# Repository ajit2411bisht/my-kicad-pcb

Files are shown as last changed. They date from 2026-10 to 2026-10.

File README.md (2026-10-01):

# ESP32-C3 PCB Design

## Overview

This project contains a custom PCB design based on the ESP32-C3.

The PCB was designed using KiCad and includes the main ESP32-C3 circuit along with sensor and user-interface sections.

## Tools Used

- KiCad

## Project Files

- `esp32demoproject.kicad_pro` - KiCad project file
- `esp32demoproject.kicad_pcb` - PCB layout
- `esp32-c3-02.kicad_sch` - ESP32-C3 schematic
- `sensors.kicad_sch` - Sensor section schematic
- `user_interface.kicad_sch` - User interface schematic

## Features

- ESP32-C3 based design
- Sensor interface
- User interface section
- Custom PCB layout
- Hierarchical schematic design

## PCB Design

The PCB layout was designed and reviewed using KiCad.

## Author

Ajit Bisht

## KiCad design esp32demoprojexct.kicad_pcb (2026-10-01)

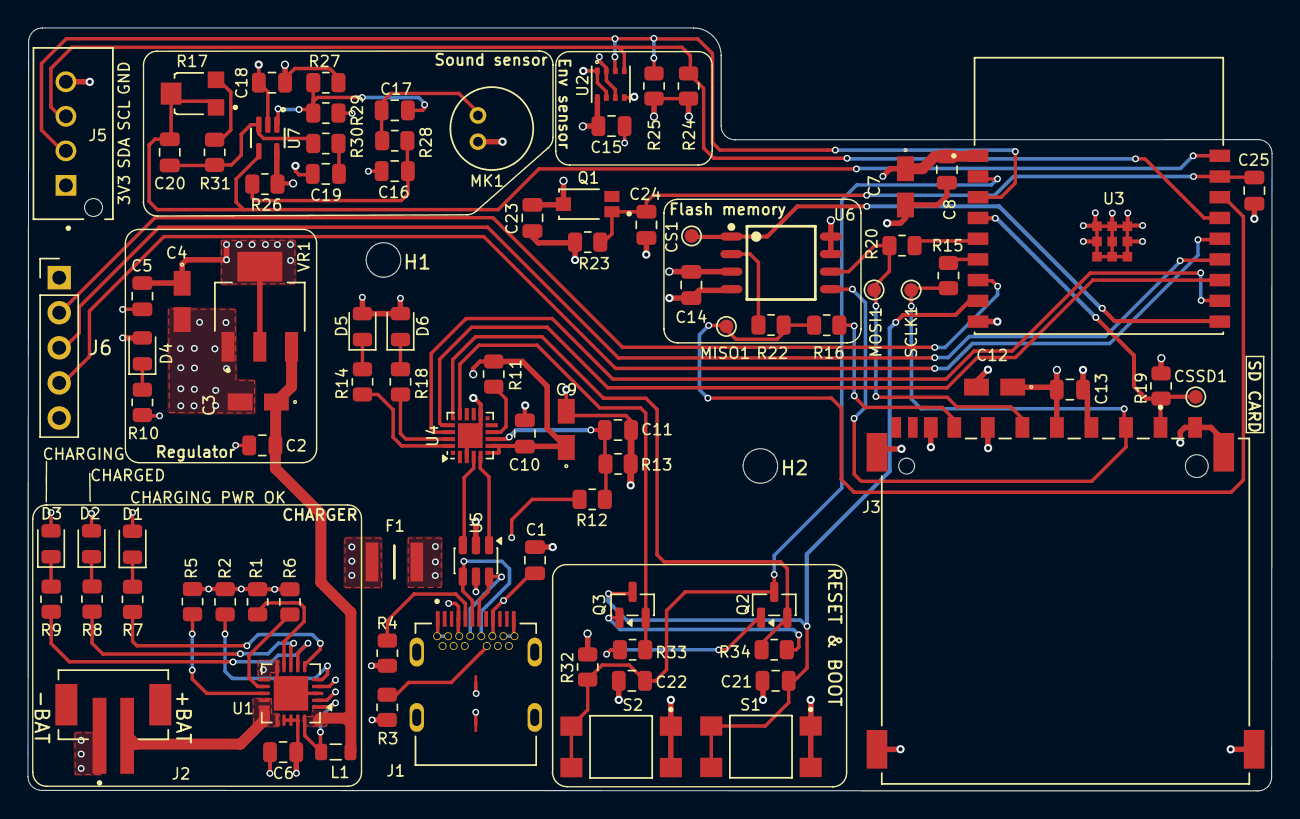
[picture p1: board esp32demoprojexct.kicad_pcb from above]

Board: 4 copper layers, 90.0 x 55.2 mm, 92 parts (0 on the bottom side), 60 nets.

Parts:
C1, C2, C5, C8, C10, C13, C14, C15, C16, C18, C19, C20, C21, C22, C23: 0.1u; C_0805_2012Metric
C3, C4, C7, C12: 10u; T491A
C6, C11: 1u; C_0805_2012Metric
C9: 4.7u; T491A
C17, C24, C25: 10n; C_0805_2012Metric
CS1: Test CS; TestPoint_Pad_D1.0mm
CSSD1: Test CS_SD; TestPoint_Pad_D1.0mm
D1: Red; LED_0805_2012Metric
D2: Green; LED_0805_2012Metric
D3: Blue; LED_0805_2012Metric
D4: red; LED_0805_2012Metric
D5: GREEN; LED_0805_2012Metric
D6: BLUE; LED_0805_2012Metric
F1: 0ZCH0110AF2E; FUSC3226X100N
H1, H2: MountingHole; MountingHole_2.5mm
J1: SS-52400-002; BELFUSE_SS-52400-002
J2: B2B-PH-SM4-TB; JST_B2B-PH-SM4-TB
J3: GSD090012SEU; AMPHENOL_GSD090012SEU
J5: B4B-XH-AM__LF__SN_; JST_B4B-XH-AM__LF__SN_
J6: Conn_01x05_Pin; PinHeader_1x05_P2.54mm_Vertical
L1: L_Ferrite; L_0805_2012Metric
MISO1: Test MISO; TestPoint_Pad_D1.0mm
MK1: CMC-5042PF-AC; CUI_CMC-5042PF-AC
MOSI1: Test MOSI; TestPoint_Pad_D1.0mm
Q1: TEMT6000X01; TRANS_TEMT6000X01
Q2, Q3: BC817; SOT-23
R1, R2, R19, R23, R30, R32, R33, R34: 10k; R_0805_2012Metric
R3: 5.1k; R_0805_2012Metric
R4: 5k1; R_0805_2012Metric
R5, R26, R28: 2k; R_0805_2012Metric
R6: 20k; R_0805_2012Metric
R7, R8, R9, R14, R18: 470; R_0805_2012Metric
R10: 330; R_0805_2012Metric
R11: 1k; R_0805_2012Metric
R12: 22K1; R_0805_2012Metric
R13: 47K5; R_0805_2012Metric
R15, R16, R20, R22: 50R; R_0805_2012Metric
R17: 35WR100KLFTR; TRIM_35WR100KLFTR
R24, R25: 4k7; R_0805_2012Metric
R27, R29: 1M; R_0805_2012Metric
R31: 22k; R_0805_2012Metric
S1: BOOT BUTTON; SW_TL3305AF260QG
S2: RESET; SW_TL3305AF260QG
SCLK1: Test SCLK; TestPoint_Pad_D1.0mm
U1: MCP73871; QFN-20-1EP_4x4mm_P0.5mm_EP2.5x2.5mm
U2: BME280; PSON65P250X250X100-8N
U3: ESP32-C3-WROOM-02-H4; MODULE_ESP32-C3-WROOM-02-H4
U4: CP2102N-Axx-xQFN20; SiliconLabs_QFN-20-1EP_3x3mm_P0.5mm_EP1.8x1.8mm
U5: USBLC6-2SC6; SOT-23-6
U6: W25Q32JVSSIQ; SOIC127P790X216-8N
U7: MAX4466EXK; SOT65P210X110-5N
VR1: LM1117MPX-3.3; VREG_LM1117MPX-3.3_NOPB

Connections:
+3.3V: C4.1, C5.1, C7.1, C8.1, C9.1, C10.2, C12.1, C13.1, C14.1, C15.1, C18.1, C23.1, D4.2 (A), D5.2 (A), D6.2 (A), J3.4 (VDD1), J5.1, J6.1, Q1.3, R11.1, R19.1, R24.1, R25.1, R26.2, R27.2, R32.2, U2.2 (CSB), U2.6 (VDDIO), U2.8 (VDD), U3.1 (3V3), U4.6 (VDD), U4.7 (VREGIN), U6.3 (~WP(IO2)), U6.7 (~HOLD/~RESET(IO3)), U6.8 (VCC), U7.5 (VCC), VR1.2 (VOUT_2), VR1.4 (VOUT_4)
+5V: C2.1, C3.1, L1.2, VR1.3 (VIN)
/+5V_USB: C6.1, D1.2 (A), D2.2 (A), D3.2 (A), F1.2, U1.2 (VPCC), U1.4 (PROG2), U1.17 (CE), U1.18 (IN), U1.19 (IN)
/CHARGED: R8.2, U1.8 (STAT1/~LBO)
/CHARGING: R9.2, U1.7 (STAT2)
/CHARGING_POWER_GOOD: R7.2, U1.6 (~PG)
/ESP32-C3-02/BOOT: C21.1, Q3.3 (C), S1.2, S1.4, U3.8 (IO9)
/ESP32-C3-02/CS: CS1.1 (1_1), U3.10 (IO10), U6.1 (~CS)
/ESP32-C3-02/CS_SD: CSSD1.1 (1_1), J3.1 (CD/DAT3), R19.2, U3.4 (IO5)
/ESP32-C3-02/DTS: Q3.2 (E), R33.1, U4.15 (~CTS)
/ESP32-C3-02/EN: C22.1, Q2.3 (C), R32.1, S2.2, S2.4, U3.2 (EN)
/ESP32-C3-02/GPIO8: J6.2, U3.7 (IO8)
/ESP32-C3-02/GPIO18: J6.3, U3.13 (IO18)
/ESP32-C3-02/GPIO19: J6.4, U3.14 (IO19)
/ESP32-C3-02/MIC_OUT: C20.2, R17.1, R17.2, U3.18 (IO0), U7.4 (OUT)
/ESP32-C3-02/MISO_DO: MISO1.1 (1_1), R16.1, R22.2, U3.16 (IO2)
/ESP32-C3-02/MOSI_DI: J3.2 (CMD), MOSI1.1 (1_1), R15.1, U6.5 (DI(IO0))
/ESP32-C3-02/PHOTO_S: C24.1, C25.1, Q1.1, R23.1, U3.17 (IO1)
/ESP32-C3-02/RTS: Q2.2 (E), R34.1, U4.16 (~RTS)
/ESP32-C3-02/RX_TX: U3.12 (TXD), U4.17 (RXD)
/ESP32-C3-02/SCL: J5.3, R24.2, U2.4 (SCK), U3.15 (IO3)
/ESP32-C3-02/SCLK: J3.5 (CLK), R20.2, SCLK1.1 (1_1), U6.6 (CLK)
/ESP32-C3-02/SDA: J5.2, R25.2, U2.3 (SDI), U3.3 (IO4)
/ESP32-C3-02/TX_RX: U3.11 (RXD), U4.18 (TXD)
/ESP32-C3-02/USB_D+: U4.4 (D+), U5.3 (I/O2)
/ESP32-C3-02/USB_D-: U4.5 (D-), U5.1 (I/O1)
/USB_DN: J1.A7 (DN1), J1.B7 (DN2), U5.6 (I/O1)
/USB_DP: J1.A6 (DP1), J1.B6 (DP2), U5.4 (I/O2)
/VBAT: J2.2, U1.14 (V_{BAT}), U1.15 (V_{BAT}), U1.16 (V_{BAT_SENSE})
/VBUS: C1.1, F1.1, J1.A4 (VBUSA1), J1.A9 (VBUSA2), J1.B4 (VBUSB1), J1.B9 (VBUSB2), R12.1, U5.5 (VBUS)
/pwr_led: D4.1 (K), R10.2
GND: C1.2, C2.2, C3.2, C4.2, C5.2, C6.2, C7.2, C8.2, C9.2, C10.1, C11.2, C12.2, C13.2, C14.2, C15.2, C16.1, C18.2, C19.1, C21.2, C22.2, C23.2, C24.2, C25.2, J1.A1 (GNDA1), J1.A12 (GNDA2), J1.B1 (GNDB1), J1.B12 (GNDB2), J1.G1 (GND/SHIELD), J1.G2 (GND/SHIELD), J1.G3 (GND/SHIELD), J1.G4 (GND/SHIELD), J1.S1 (GND/SHIELD), J1.S2 (GND/SHIELD), J1.S3 (GND/SHIELD), J1.S4 (GND/SHIELD), J2.1, J3.3 (VSS1), J3.6 (VSS2), J3.8 (DAT1), J3.9 (DAT2), J3.G1 (SHIELD_GND), J3.G2 (SHIELD_GND), J3.G3 (SHIELD_GND), J3.G4 (SHIELD_GND), J5.4, J6.5, MK1.GND, R1.2, R2.2, R3.1, R4.1, R5.1, R6.1, R10.1, R13.2, R23.2, R29.1, S1.1, S1.3, S2.1, S2.3, U1.3 (SEL), U1.10 (V_{SS}), U1.11 (V_{SS}), U1.21 (V_{SS}), U2.1 (GND), U2.5 (SDO), U2.7 (GND), U3.9 (GND), U3.19 (GND), U3.20 (GND), U3.21 (GND), U3.22 (GND), U3.23 (GND), U3.24 (GND), U3.25 (GND), U3.26 (GND), U3.27 (GND), U4.3 (GND), U4.12 (GND), U4.21 (GND), U5.2 (GND), U6.4 (GND), U7.2 (GND), VR1.1 (GND)
unnamed: C16.2, R26.1, R28.2
unnamed: C17.1, MK1.OUT, R28.1
unnamed: C19.2, R30.1
unnamed: D1.1 (K), R7.1
unnamed: D2.1 (K), R8.1
unnamed: D3.1 (K), R9.1
unnamed: D5.1 (K), R14.1
unnamed: D6.1 (K), R18.1
unnamed: J1.A5 (CC1), R4.2
unnamed: J1.B5 (CC2), R3.2
unnamed: J3.7 (DAT0), R16.2
unnamed: L1.1, U1.1 (OUT), U1.20 (OUT)
unnamed: Q2.1 (B), R33.2
unnamed: Q3.1 (B), R34.2
unnamed: R17.3, R31.2
unnamed: R5.2, U1.13 (PROG1)
unnamed: R6.2, U1.12 (PROG3)
unnamed: R2.1, U1.5 (THERM)
unnamed: R1.1, U1.9 (~TE)
unnamed: R20.1, U3.5 (IO6)
unnamed: R15.2, U3.6 (IO7)
unnamed: C11.1, R12.2, R13.1, U4.8 (VBUS)
unnamed: R11.2, U4.9 (~RST)
unnamed: R18.2, U4.19 (~RXT/GPIO.3)
unnamed: R14.2, U4.20 (~TXT/GPIO.2)
unnamed: R22.1, U6.2 (DO(IO1))
unnamed: C17.2, R27.1, R29.2, U7.1 (IN+)
unnamed: C20.1, R30.2, R31.1, U7.3 (IN-)

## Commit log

2026-10-01 Initial KiCad PCB design
    [esp32-c3-02.kicad_sch, esp32demoprojexct.kicad_pcb, sensors.kicad_sch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]
2026-10-01 Add README.md for ESP32-C3 PCB design project
